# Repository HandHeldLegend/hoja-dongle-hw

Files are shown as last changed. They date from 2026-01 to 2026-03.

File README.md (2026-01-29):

## Hoja Dongle Hardware
This is designed to be an open source dongle for Handheldlegend gamepads. 

This is essentially a Pico 2 W in a more compact form-factor, with a USB-C connector that has additional pins connected for retro game console compatibility. 
These pins use logic level translation to ensure that 5V on the pins will not damage the RP2354A Microcontroller.

Since the RM2 module is Wifi and Bluetooth capable, this could be used in many other interesting ways. 



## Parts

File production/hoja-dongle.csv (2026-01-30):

# | Reference | Qty | MPN | Description | Value | Package | Link | LCSC | DNP | Footprint
1 | R13 | 1 | 0201WMF5102TEE0201WMF5102TEE | RES 51kΩ ±1% 50mW 0201 | 51K | 0201 | https://www.lcsc.com/product-detail/C473471.html | C473471 |  | Resistor_SMD:R_0201_0603Metric
2 | SW1 | 1 | 1TS026A-1000-0550 | 50mA 2.6mm 100MΩ 200,000 Times 12V 100gf 1.6mm 0.55mm Round Button Standing paste SPST SMD,1.6x2.6mm Tactile Switches ROHS | 1TS026A-1000-0550 | SMD,1.6x2.6mm | https://www.lcsc.com/product-detail/Tactile-Switches_HYP-Hongyuan-Precision-1TS026A-1000-0550-CT_C913778.html | C913778 |  | hhl:1TS026A-1000-0550
3 | Y1 | 1 | ABM8-272-T3 | 12MHz SMD3225-4P Crystals ROHS | ABM8-272-T3 | SMD3225-4P |  | C20625731 |  | Crystal:Crystal_SMD_3225-4Pin_3.2x2.5mm
4 | R22 | 1 | AC0201FR-07470RL | 50mW Thick Film Resistors ±1% ±200ppm/℃ 470Ω 0201 Chip Resistor - Surface Mount ROHS | 470R | 0201 |  | C226558 |  | Resistor_SMD:R_0201_0603Metric
5 | L4 | 1 | AOTA-B201610S3R3-101-T | 0806 POLARIZED Fixed Inductors RoHS | 3.3u |  |  | C42411119 |  | hhl:L_pol_2016
6 | L5 | 1 | BLM18AG601SN1D | Murata Electronics Ferrite Bead | BLM18AG601SN1D | 0603 |  | C19330 |  | Inductor_SMD:L_0603_1608Metric
7 | Q1,Q2 | 2 | BSS138DW-7-F | 50V 200mA 200mW 3.5Ω@10V,220mA 1.5V@250uA 2 N-Channel SC-70-6(SOT-363) MOSFETs ROHS | BSS138DW | SC-70-6(SOT-363) |  | C154900 |  | Package_TO_SOT_SMD:SOT-363_SC-70-6
8 | C1,C2 | 2 | CC0402FRNPO9BN150 | 50V 15pF NP0 ±1% | 15pF | 0402 |  | C326803 |  | Capacitor_SMD:C_0402_1005Metric
9 | C6 | 1 | CC0402KRX7R5BB104 | 6.3V 100nF X7R ±10% | 100nF | 0402 |  | C541406 |  | Capacitor_SMD:C_0402_1005Metric
10 | C5,C7,C9,C10 | 4 | CL05A475KP5NRNC | 10V 4.7uF X5R ±10% 0402 Ceramic Capacitors RoHS | 4.7u |  |  | C368809 |  | Capacitor_SMD:C_0402_1005Metric
11 | C4,C11 | 2 | CL21A106KPFNNNE | 10V 10uF X5R ±10% | 10uF | 0805 |  | C17024 |  | Capacitor_SMD:C_0805_2012Metric
12 | D1,D2,D3 | 3 | CUS08F30,H3F | SOD-323 Schottky Diodes ROHS | CUS08F30,H3F | SOD-323 |  | C150183 |  | Diode_SMD:D_SOD-323_HandSoldering
13 | C8,C12,C13,C14,C15,C16,C17,C18,C19,C20,C21 | 11 | GRM033R61A104KE15D | 10V 100nF X5R ±10% 0201 Ceramic Capacitors RoHS | 100n |  |  | C76934 |  | Capacitor_SMD:C_0201_0603Metric
14 | SW2,SW3 | 2 | KSC201J LFS | Soft 160gf actuator, 3.5mm height tactile button IP67 | SW_Push |  |  | C221725 |  | hhl:KSC-TE
15 | L3 | 1 | MIP25202R2MBE | 1.3A 2.2uH ±20% 80mΩ 1008 Inductors (SMD) ROHS | 1.3A 2.2uH ±20% 80mΩ | 1008 |  | C315721 |  | Inductor_SMD:L_1008_2520Metric
16 | R14 | 1 | RC0201FR-0710KL | 50mW Thick Film Resistors 25V ±1% ±200ppm/℃ 10kΩ | 10k | 0201 |  | C106225 |  | Resistor_SMD:R_0201_0603Metric
17 | R17,R18,R19,R20,R21 | 5 | RC0201FR-0727RL | Resistor | 27R | 0201 | https://www.lcsc.com/product-detail/Chip-Resistor-Surface-Mount_YAGEO-RC0201FR-0727RL_C273268.html | C273268 |  | Resistor_SMD:R_0201_0603Metric
18 | R12 | 1 | RC0201FR-0733RL | Resistor | 33 |  |  | C295794 |  | Resistor_SMD:R_0201_0603Metric
19 | R7,R11,R15,R16 | 4 | RC0201FR-07100RL | 62.5mW Thick Film Resistors 50V ±100ppm/℃ ±1% 100Ω | 100R | 0201 | https://www.lcsc.com/product-detail/Chip-Resistor-Surface-Mount_YAGEO-RC0201FR-0727RL_C273268.html | C77623 |  | Resistor_SMD:R_0201_0603Metric
20 | R1,R2,R3,R4,R5,R6,R10 | 7 | RC0402FR-071KL | 62.5mW Thick Film Resistors 50V ±100ppm/℃ ±1% 1kΩ | 1k | 0402 |  | C106235 |  | Resistor_SMD:R_0402_1005Metric
21 | R8,R9 | 2 | RC0402FR-075K1L | 62.5mW Thick Film Resistors 50V ±100ppm/℃ ±1% 5.1kΩ | 5.1k | 0402 |  | C105872 |  | Resistor_SMD:R_0402_1005Metric
22 | U5 | 1 | RP2354A | QFN-60(7x7) Microcontrollers RoHS | RP2350_60QFN |  |  | C41378174 |  | hhl:RP2350-QFN-60-1EP_7x7_P0.4mm_EP3.4x3.4mm_ThermalVias
23 | P1 | 1 | RPI-RM2 | Raspberry Pi RM2 Wireless Module | RPI-RM2 |  |  | ~ |  | hhl:RPI_RM2
24 | L1,L2 | 2 | SK6805-EC-10 | 0606 RGB LEDs(Built-in IC) ROHS | SK6805-EC-10 | 0606 |  |  |  | hhl:SK6805-EC-10
25 | C3 | 1 | TAJA476K006RNJ |  | 47uF |  |  | C7190 |  | Capacitor_Tantalum_SMD:CP_EIA-3216-18_Kemet-A
26 | U4 | 1 | TPS63001DRCR | High efficiency Buck-Boost Converter with 1.8A Current Switches in 3x3 QFN | TPS630001RCR | VSON-10 Texas Instruments |  | C28060 |  | hhl:VREG_V62_16624-01YE
27 | J2 | 1 | USB4080-03-A | CONN RCPT USB C 3.2 24POS SMD RA | USB4080-03-A_REVA1 | None | https://www.digikey.com/en/products/detail/gct/USB4080-03-A/14659819 |  |  | dongle:GCT_USB4080-03-A_REVA1
28 | U1,U2,U3 | 3 | USBLC6-2P6 | Very low capacitance ESD protection diode, 2 data-line, SOT-666 | USBLC6-2P6 | SOT-666-6 | https://www.lcsc.com/product-detail/C15999.html?s_z=n_USBLC6-2P6 | C15999 |  | Package_TO_SOT_SMD:SOT-666

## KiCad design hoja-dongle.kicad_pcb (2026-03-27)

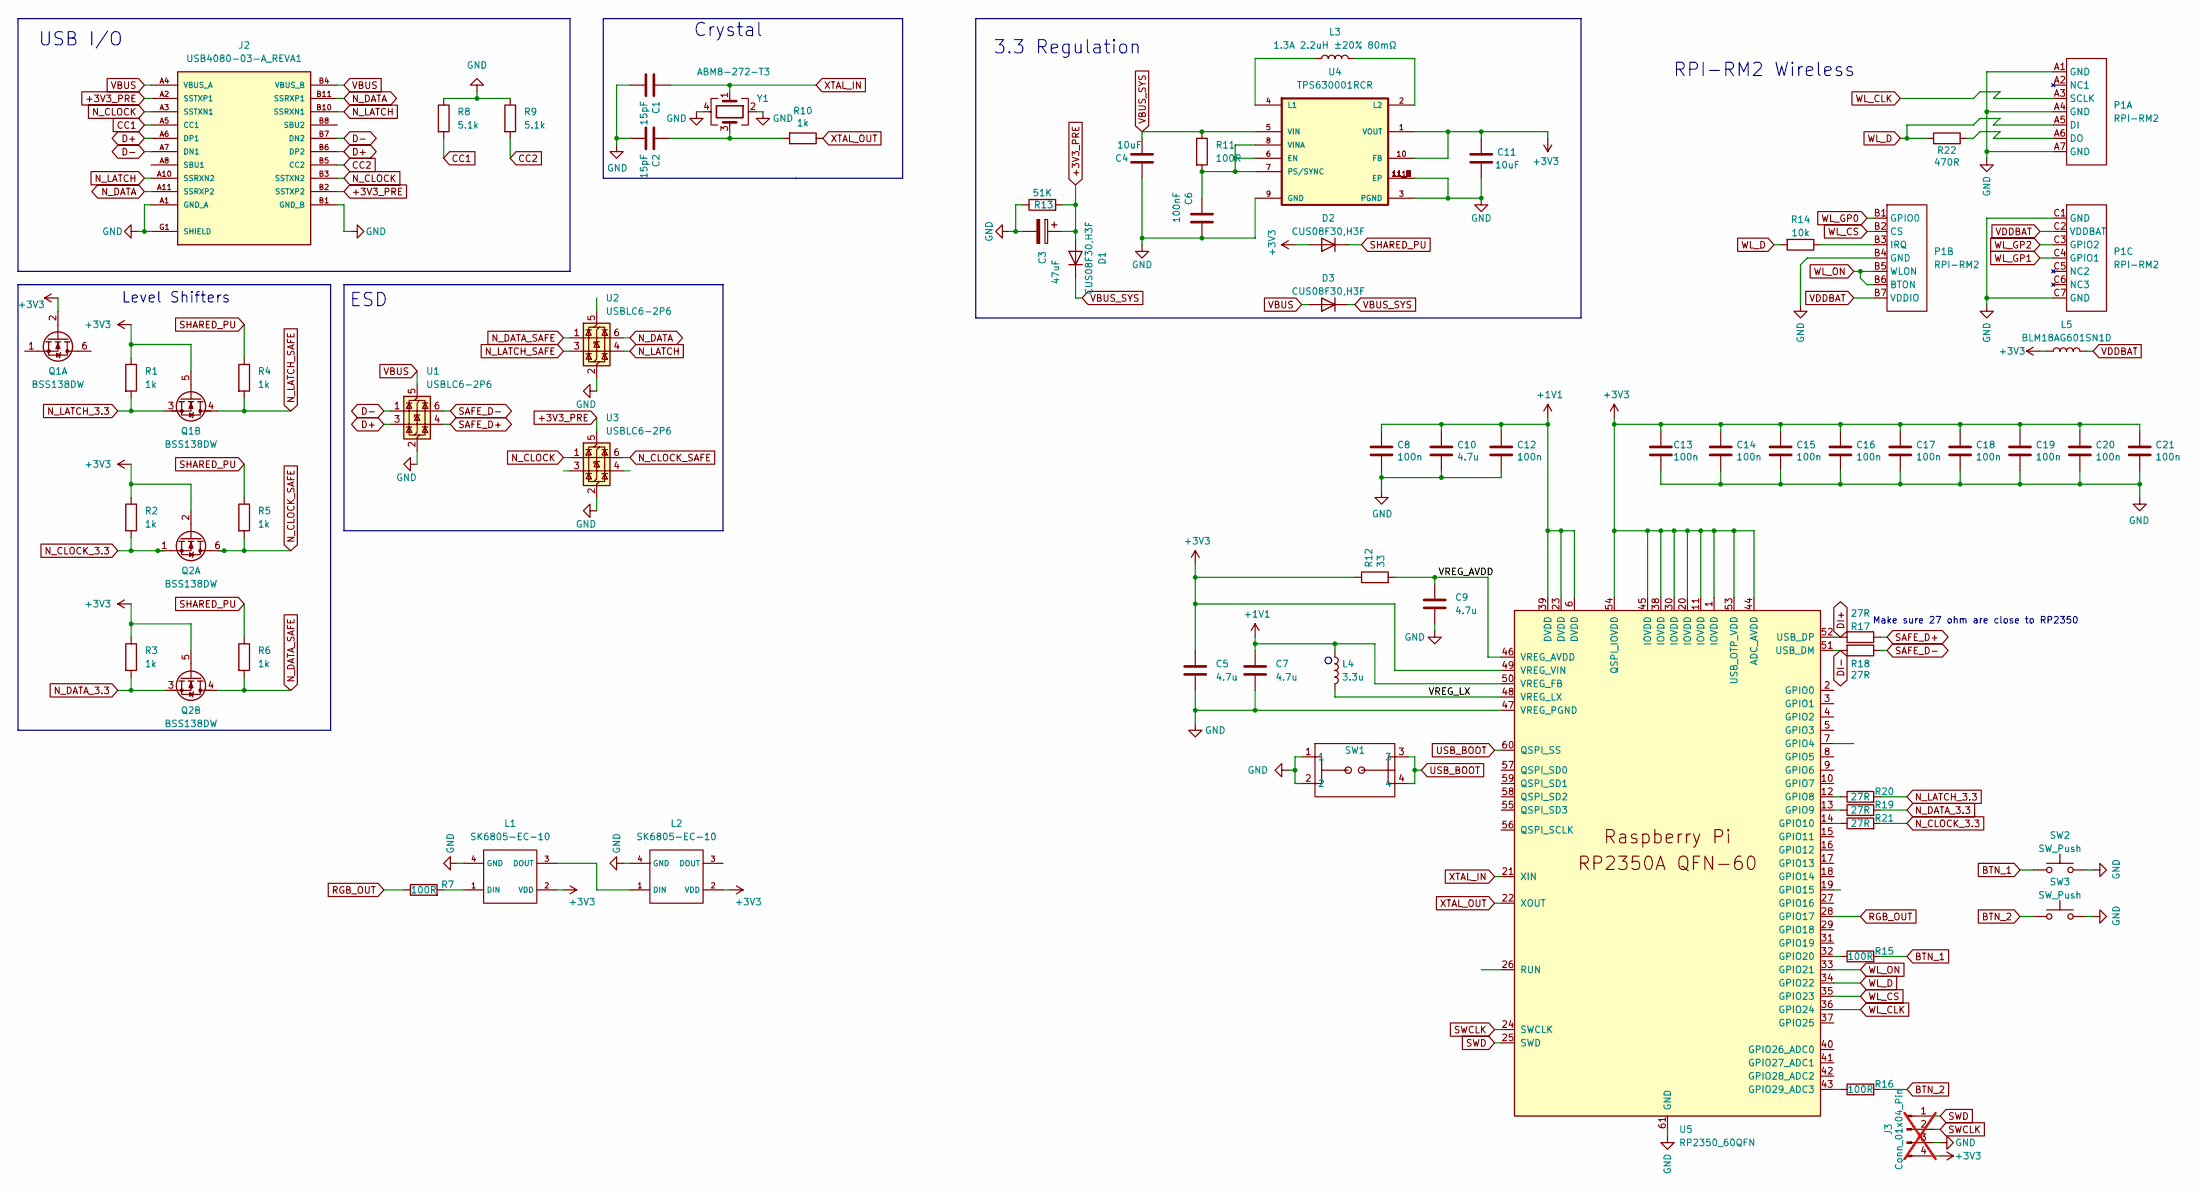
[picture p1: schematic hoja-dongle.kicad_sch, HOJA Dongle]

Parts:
C1, C2: 15pF; C_0402_1005Metric; MPN CC0402FRNPO9BN150; LCSC C326803
C3: 47uF; CP_EIA-3216-18_Kemet-A; MPN TAJA476K006RNJ; LCSC C7190
C4, C11: 10uF; C_0805_2012Metric; MPN CL21A106KPFNNNE; LCSC C17024
C5, C7, C9, C10: 4.7u; C_0402_1005Metric; MPN CL05A475KP5NRNC; LCSC C368809
C6: 100nF; C_0402_1005Metric; MPN CC0402KRX7R5BB104; LCSC C541406
C8, C12, C13, C14, C15, C16, C17, C18, C19, C20, C21: 100n; C_0201_0603Metric; MPN GRM033R61A104KE15D; LCSC C76934
D1, D2, D3: CUS08F30,H3F; D_SOD-323_HandSoldering; MPN CUS08F30,H3F; LCSC C150183
J2: USB4080-03-A_REVA1; GCT_USB4080-03-A_REVA1; PARTREV A1
J3: Conn_01x04_Pin; PinHeader_1x04_P2.00mm_Vertical; not fitted
L1, L2: SK6805-EC-10; MPN SK6805-EC-10
L3: 1.3A 2.2uH ±20% 80mΩ; L_1008_2520Metric; MPN MIP25202R2MBE; LCSC C315721
L4: 3.3u; L_pol_2016; MPN AOTA-B201610S3R3-101-T; LCSC C42411119
L5: BLM18AG601SN1D; L_0603_1608Metric; MPN BLM18AG601SN1D; LCSC C19330
P1: RPI-RM2; RPI_RM2; MPN RPI-RM2
Q1, Q2: BSS138DW; SOT-363_SC-70-6; MPN BSS138DW-7-F; LCSC C154900
R1, R2, R3, R4, R5, R6, R10: 1k; R_0402_1005Metric; MPN RC0402FR-071KL; LCSC C106235
R7, R11, R15, R16: 100R; R_0201_0603Metric; MPN RC0201FR-07100RL; LCSC C77623
R8, R9: 5.1k; R_0402_1005Metric; MPN RC0402FR-075K1L; LCSC C105872
R12: 33; R_0201_0603Metric; MPN RC0201FR-0733RL; LCSC C295794
R13: 51K; R_0201_0603Metric; MPN 0201WMF5102TEE0201WMF5102TEE; LCSC C473471
R14: 10k; R_0201_0603Metric; MPN RC0201FR-0710KL; LCSC C106225
R17, R18, R19, R20, R21: 27R; R_0201_0603Metric; MPN RC0201FR-0727RL; LCSC C273268
R22: 470R; R_0201_0603Metric; MPN AC0201FR-07470RL; LCSC C226558
SW1: 1TS026A-1000-0550; MPN 1TS026A-1000-0550; LCSC C913778
SW2, SW3: SW_Push; KSC-TE; MPN KSC201J LFS; LCSC C221725
U1, U2, U3: USBLC6-2P6; SOT-666; MPN USBLC6-2P6; LCSC C15999
U4: TPS630001RCR; VREG_V62_16624-01YE; MPN TPS63001DRCR; LCSC C28060
U5: RP2350_60QFN; RP2350-QFN-60-1EP_7x7_P0.4mm_EP3.4x3.4mm_ThermalVias; MPN RP2354A; LCSC C41378174
Y1: ABM8-272-T3; Crystal_SMD_3225-4Pin_3.2x2.5mm; MPN ABM8-272-T3; LCSC C20625731

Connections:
+1V1: C7.1, C8.1, C10.1, C12.1, L4.1, U5.6 (DVDD), U5.23 (DVDD), U5.39 (DVDD), U5.50 (VREG_FB)
+3V3: C5.1, C11.1, C13.1, C14.1, C15.1, C16.1, C17.1, C18.1, C19.1, C20.1, C21.1, D2.2 (A), J3.4, L1.2 (VDD), L2.2 (VDD), L5.1, Q1.2 (G1), Q1.5 (G2), Q2.2 (G1), Q2.5 (G2), R1.1, R2.1, R3.1, R12.1, U4.1 (VOUT), U4.10 (FB), U5.1 (IOVDD), U5.11 (IOVDD), U5.20 (IOVDD), U5.30 (IOVDD), U5.38 (IOVDD), U5.44 (ADC_AVDD), U5.45 (IOVDD), U5.49 (VREG_VIN), U5.53 (USB_OTP_VDD), U5.54 (QSPI_IOVDD)
+3V3_PRE: C3.1, D1.2 (A), J2.A2 (SSTXP1), J2.B2 (SSTXP2), R13.2, U3.5 (VBUS)
/VREG_AVDD: C9.1, R12.2, U5.46 (VREG_AVDD)
/VREG_LX: L4.2, U5.48 (VREG_LX)
BTN_1: R15.2, SW2.1
BTN_2: R16.2, SW3.1
CC1: J2.A5 (CC1), R8.2
CC2: J2.B5 (CC2), R9.2
D+: J2.A6 (DP1), J2.B6 (DP2), U1.3 (I/O2)
D-: J2.A7 (DN1), J2.B7 (DN2), U1.1 (I/O1)
DI+: R17.2, U5.52 (USB_DP)
DI-: R18.2, U5.51 (USB_DM)
GND: C1.2, C2.2, C3.2, C4.1, C5.2, C6.1, C7.2, C8.2, C9.2, C10.2, C11.2, C12.2, C13.2, C14.2, C15.2, C16.2, C17.2, C18.2, C19.2, C20.2, C21.2, J2.A1 (GND_A), J2.A12 (GND_A), J2.B1 (GND_B), J2.B12 (GND_B), J2.G1 (SHIELD), J2.G2 (SHIELD), J2.G3 (SHIELD), J2.G4 (SHIELD), J3.3, L1.4 (GND), L2.4 (GND), P1.A1 (GND), P1.A4 (GND), P1.A7 (GND), P1.B4 (GND), P1.C1 (GND), P1.C7 (GND), R8.1, R9.1, R13.1, SW1.1, SW1.2, SW2.2, SW3.2, U1.2 (GND), U2.2 (GND), U3.2 (GND), U4.3 (PGND), U4.9 (GND), U4.11 (EP), U4.11_1 (EP), U4.11_2 (EP), U4.11_3 (EP), U4.11_4 (EP), U4.11_5 (EP), U4.11_6 (EP), U4.11_7 (EP), U4.11_8 (EP), U5.47 (VREG_PGND), U5.61 (GND), Y1.2, Y1.4
N_CLOCK: J2.A3 (SSTXN1), J2.B3 (SSTXN2), U3.1 (I/O1)
N_CLOCK_3.3: Q2.1 (S1), R2.2, R21.2
N_CLOCK_SAFE: Q2.6 (D1), R5.2, U3.6 (I/O1)
N_DATA: J2.A11 (SSRXP2), J2.B11 (SSRXP1), U2.6 (I/O1)
N_DATA_3.3: Q2.3 (D2), R3.2, R19.2
N_DATA_SAFE: Q2.4 (S2), R6.2, U2.1 (I/O1)
N_LATCH: J2.A10 (SSRXN2), J2.B10 (SSRXN1), U2.4 (I/O2)
N_LATCH_3.3: Q1.3 (D2), R1.2, R20.2
N_LATCH_SAFE: Q1.4 (S2), R4.2, U2.3 (I/O2)
unnamed: C2.1, R10.2, Y1.3
unnamed: L1.1 (DIN), R7.2
unnamed: L1.3 (DOUT), L2.1 (DIN)
unnamed: P1.A6 (DO), R22.2
unnamed: P1.B3 (IRQ), R14.1
unnamed: C6.2, R11.2, U4.6 (EN), U4.7 (PS/SYNC), U4.8 (VINA)
unnamed: L3.1, U4.4 (L1)
unnamed: L3.2, U4.2 (L2)
unnamed: R20.1, U5.12 (GPIO8)
unnamed: R19.1, U5.13 (GPIO9)
unnamed: R21.1, U5.14 (GPIO10)
unnamed: R15.1, U5.32 (GPIO20)
unnamed: R16.1, U5.43 (GPIO29_ADC3)
RGB_OUT: R7.1, U5.28 (GPIO17)
SAFE_D+: R17.1, U1.4 (I/O2)
SAFE_D-: R18.1, U1.6 (I/O1)
SHARED_PU: D2.1 (K), R4.1, R5.1, R6.1
SWCLK: J3.2, U5.24 (SWCLK)
SWD: J3.1, U5.25 (SWD)
USB_BOOT: SW1.3, SW1.4, U5.60 (QSPI_SS)
VBUS: D3.2 (A), J2.A4 (VBUS_A), J2.A9 (VBUS_A), J2.B4 (VBUS_B), J2.B9 (VBUS_B), U1.5 (VBUS)
VBUS_SYS: C4.2, D1.1 (K), D3.1 (K), R11.1, U4.5 (VIN)
VDDBAT: L5.2, P1.B7 (VDDIO), P1.C2 (VDDBAT)
WL_CLK: P1.A3 (SCLK), U5.36 (GPIO24)
WL_CS: P1.B2 (CS), U5.35 (GPIO23)
WL_D: P1.A5 (DI), R14.2, R22.1, U5.34 (GPIO22)
WL_GP0: P1.B1 (GPIO0)
WL_GP1: P1.C4 (GPIO1)
WL_GP2: P1.C3 (GPIO2)
WL_ON: P1.B5 (WLON), P1.B6 (BTON), U5.33 (GPIO21)
XTAL_IN: C1.1, U5.21 (XIN), Y1.1
XTAL_OUT: R10.1, U5.22 (XOUT)

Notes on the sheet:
RPI-RM2 Wireless
Crystal
USB I/O
Make sure 27 ohm are close to RP2350
3.3 Regulation
Level Shifters
ESD

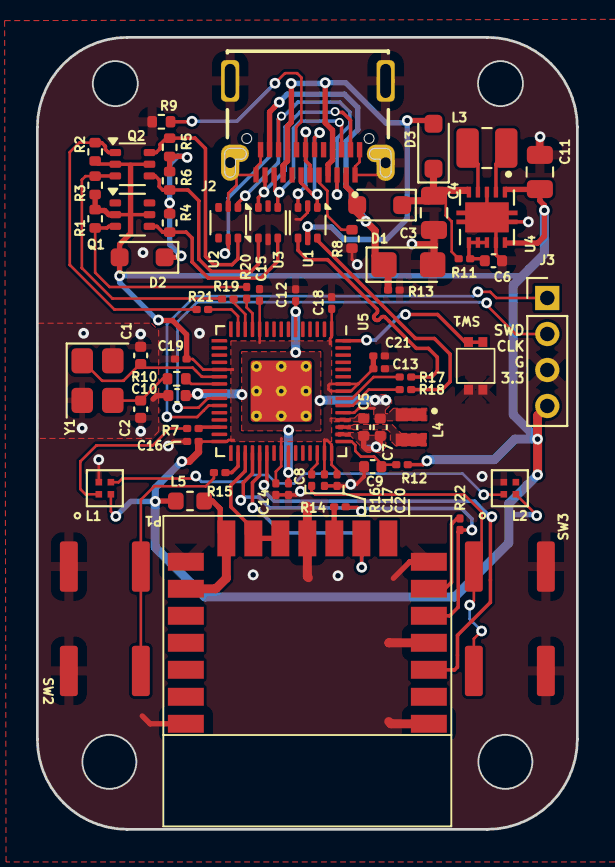
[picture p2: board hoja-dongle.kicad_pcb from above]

Board: 2 copper layers, 30.0 x 44.0 mm, 65 parts (0 on the bottom side), 52 nets.
